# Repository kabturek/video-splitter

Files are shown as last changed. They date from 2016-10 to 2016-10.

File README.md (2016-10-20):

# Video Splitter

**This design is UNTESTED - the pcb was sent to the fab house 16.10.2016.**

This is a simple 2 channel video splitter for FPV use (but can be use with any analog signal).
It uses servo connectors for video in/out but you can solder wires directly to
the pads. Power pin is just a passthru between the 3 connectors (and it powers
the regulator). 

## Design

This is really a mashup of 2 reference designs - IA171 and LP2985 so no big
innovation here. According to the datasheet the IA171 can drive to 75ohm loads.

## Power supply

The splitter was designed to be powered by 5-16v if a 3.3v voltage regulator is used (LP2985 or mic5205). 
The IA171 can be powered by 2.8-5.5V so its possible to use it without any voltage regulator if you have a stable 
power supply in that range - bridge pins 1 and 5 (top pins) of the VREG and
applu 2.8-5.5v to any of the 3 pin connectors (middle pin).

## [BOM](BOM.csv)

| "Qty" | "Value" | "Device" | "Package" | "Parts" | "Description" | "Link" |
|---|---|---|---|---|---|----|
| "3" | "" | "M03LOCK" | "1X03_LOCK" | "VIN, VOUT1, VOUT2" | "Header 3" | "" |
| "1" | "0.1uF" | "CAP0805" | "0805" | "C1" | "Capacitor" | "" |
| "1" | "100uF" | "CAP_POL3528" | "EIA3528" | "C3" | "Capacitor Polarized" | "" |
| "1" | "10nF" | "CERAMIC-10NF-50V-5%-X7R(0805)" | "C0805" | "C7" | "302010175" | "" |
| "3" | "22uF" | "CAP_POL1206" | "EIA3216" | "C2, C4, C6" | "Capacitor Polarized" | "" |
| "3" | "75R" | "RESISTOR0805-RES" | "0805" | "R1, R2, R3" | "Resistor" | "" |
| "1" | "IA171" | "IA171" | "SOT23-6" | "U$1" | "" | "" |
| "1" | "LP2985-33DBVR" | "PMIC-LP2985-33DBVR(SOT23-5)" | "SOT-23-5"  | "VREG" | "310030033" | "" |

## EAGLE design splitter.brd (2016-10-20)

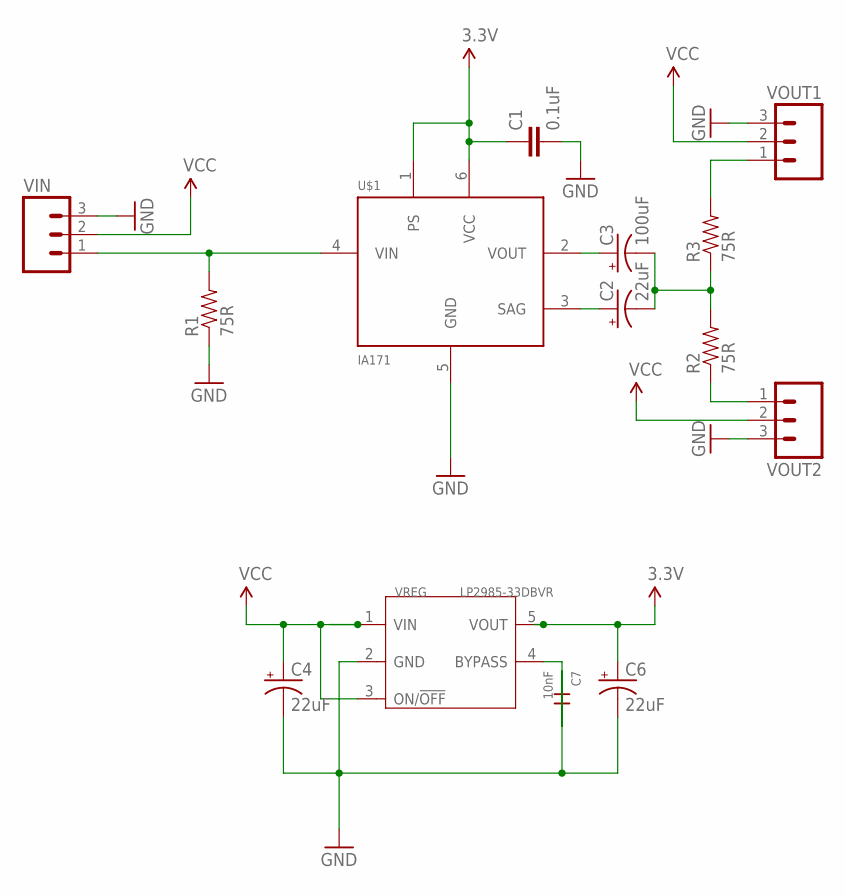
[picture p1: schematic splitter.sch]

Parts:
C1: 0.1uF; 0805
C2, C4, C6: 22uF; EIA3216
C3: 100uF; EIA3528
C7: 10nF; C0805
R1, R2, R3: 75R; 0805
U$1: IA171; SOT23-6
VIN: M03LOCK; 1X03_LOCK
VOUT1, VOUT2: M03LOCK; 1X03_LOCK
VREG: LP2985-33DBVR; SOT-23-5

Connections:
3.3V: C1.1, C6.A (+), U$1.1 (PS), U$1.6 (VCC), VREG.5 (VOUT)
GND: C1.2, C4.C (-), C6.C (-), C7.1, R1.1, U$1.5 (GND), VIN.3, VOUT1.3, VOUT2.3, VREG.2 (GND)
unnamed: C7.2, VREG.4 (BYPASS)
unnamed: R2.1, VOUT2.1
unnamed: R3.2, VOUT1.1
unnamed: C3.A (+), U$1.2 (VOUT)
unnamed: C2.A (+), U$1.3 (SAG)
unnamed: C2.C (-), C3.C (-), R2.2, R3.1
unnamed: R1.2, U$1.4 (VIN), VIN.1
VCC: C4.A (+), VIN.2, VOUT1.2, VOUT2.2, VREG.1 (VIN), VREG.3 (ON/!OFF)

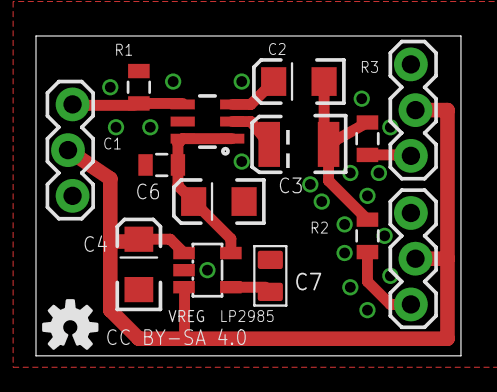
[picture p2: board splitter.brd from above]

Board: 2 copper layers, 23.6 x 17.8 mm, 16 parts (1 on the bottom side), 10 nets.

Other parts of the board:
U$2, U$3: OSHW-LOGO-S

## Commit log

2016-10-16 Add Video splitter schematic and board files
    [splitter.brd, splitter.sch]
2016-10-16 Added gihub link to the board
    [splitter.brd]
2016-10-17 Standardized the capacitors and increased their values for VREG IN/OUT
    [splitter.brd, splitter.sch]
2016-10-17 ERC changes
    [splitter.brd]
2016-10-17 fixed schematic layout
    [splitter.brd, splitter.sch]
2016-10-17 cosmetic changes on the board layout
    [splitter.brd]
2016-10-17 last minute changes
    [splitter.brd, splitter.sch]
2016-10-20 Added BOM
    [BOM.csv]
2016-10-20 update BOM after fixing component values
    [BOM.csv]
2016-10-20 fixed cap values
    [splitter.brd, splitter.sch]
2016-10-20 added gerber files generated for Seeedstudio
    [splitter.GBL, splitter.GBO, splitter.GBP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]

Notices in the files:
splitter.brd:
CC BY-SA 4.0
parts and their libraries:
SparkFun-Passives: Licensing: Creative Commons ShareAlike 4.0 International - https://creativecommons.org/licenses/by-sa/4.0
